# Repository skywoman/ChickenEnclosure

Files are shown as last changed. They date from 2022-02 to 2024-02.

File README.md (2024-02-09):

# ChickenEnclosure
Plans for enclosures for chickens, including 3D CAD models, manufacturing drawings, and sourcing guides. Variations for wheels, skids, and different sizes may be developed easily from a common base structure.

The first complete version of this enclosure uses u-bolts to attach the hoop to the frame.

[View the model in your browser here.](https://skywoman.github.io/ChickenEnclosure/Hoop%20Connection%20-%20U%20Bolts/UBoltModel.xhtml)

[Download the full 3D CAD model, bill of materials and sourcing guide, and manufacturing drawings here.](https://github.com/skywoman/ChickenEnclosure/releases/tag/v1.0.0) This includes each of the necessary components and sub-assemblies to build the full frame.

[The project webpage can be found here](https://skywoman.github.io/ChickenEnclosure/)

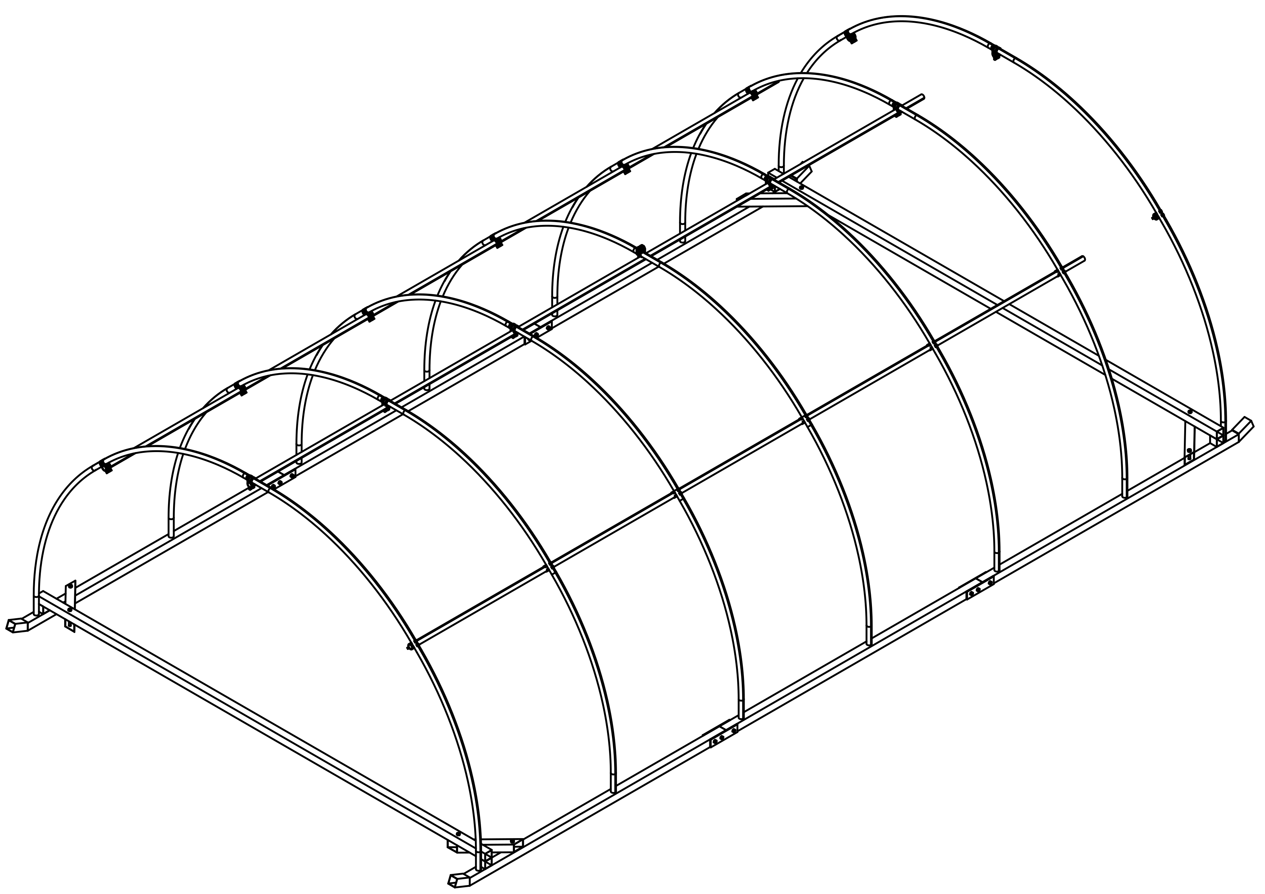
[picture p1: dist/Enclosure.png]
Wire Drawing


As designed, the materials cost is just over $1700 (USD). Depending on the conditions in your area, 2 inch square tube with a thinner wall can be substituted for 2.5 inch tube. Both materials and links are listed in the sourcing guide. Smaller, thinner-walled material will reduce the cost considerably at the expense of strength and durability. 

The design is inspired by the APPPA design, [which can be found here](https://www.apppa.org/resources/Documents/building%20a%20multi%20purpose%20pasture%20shelter.pdf).

CAD models are made in [FreeCAD](https://www.freecadweb.org), a free and open source modeling software.
Assemblies are made with the A2+ workbench, found in the Add-On Manager.

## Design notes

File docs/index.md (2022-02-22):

## Skywoman Chicken Enclosure
The Skywoman chicken enclosure is a simple-to-manufacture enclsoure for 300 birds. The design is simple enough to easily adapt to a variety of climate and predator conditions.

[VIEW THE MODEL HERE](model.xhtml)

Wire Drawing

The enclosure is a simple hoop house design, using square tubing for the base and round tubing for the hoops. The base model is moved on skids.

### Project Inspiration
The design of this enclosure is loosely based on the [APPPA design](https://www.apppa.org/resources/Documents/building%20a%20multi%20purpose%20pasture%20shelter.pdf), but has been modified to improve manufacturability and part sourcing.

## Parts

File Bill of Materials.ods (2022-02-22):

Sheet: Components
ITEM # | DESCRIPTION | QTY | SUPPLIER/MATERIAL | SUPPLIER IDENTIFIER | UNIT PRICE | TOTAL PRICE | CAD FILENAME
1 | Hoop Half Female | 7 |  |  |  | $0.00 | Hoop Half Female.FCStd
2 | Hoop Half Male | 7 |  |  |  | $0.00 | Hoop Half Male.FCStd
3 | Purlin | 3 |  |  |  | $0.00 | Purlin.FCStd
4 | Cross Connector Purlin Clamp | 21 | Tunnel Vision Hoops | https://www.tunnelvisionhoops.com/cross-connector-greenhouse-straps-purlin-clamps/ | $2.41 | $50.61 | Cross Connector Purlin Clamp.FCStd
5 | Front Bar | 2 | Square Tube | * | $129.02 | $258.03 | Front Bar.FCStd
6 | Side Front Bar | 2 | Square Tube | * | $73.72 | $147.45 | Side Front Bar.FCStd
7 | Spacer 2.5 Inch | 4 | Square Tube | * | $1.92 | $7.68 | Spacer 2.5 Inch.FCStd
8 | Corner Brace | 4 | Square Tube | * | $18.43 | $73.72 | Corner Brace.FCStd
9 | Side Rail Joint Plate | 8 | Steel Plate | * |  | $0.00 | Side Rail Joint Plate.FCStd
10 | Side Center Bar | 2 | Square Tube | * | $73.72 | $147.45 | Side Center Bar.FCStd
11 | Side Rear Bar | 2 | Square Tube | * | $73.72 | $147.45 | Side Rear Bar.FCStd
12 | Hex Head Bolt 0.500x5.50 Inch | 8 | Bolt Depot | 256 | $1.45 | $11.60 | Hex Head Bolt 0.500x5.50 Inch .FCStd
13 | Hex Head Bolt 0.500x3.50 Inch | 12 | Bolt Depot | 252 | $0.87 | $10.44 | Hex Head Bolt 0.500x3.50 Inch .FCStd
14 | Hex Nut 0.50 Inch | 20 | Bolt Depot | 2652 | $0.22 | $4.40 | Hex Nut 0.50 Inch.FCStd
15 | Skid Angled Foot | 4 | Square Tube | * |  | $0.00 | Skid Angled Foot.FCStd
16 | Hoop Attachment Peg | 14 | Lowes | https://www.lowes.com/pd/Mueller-Proline-5-1-2-in-L-x-1-2-in-x-1-2-in-dia-Black-Steel-Nipple-Fitting/3392746 | $4.58 | $64.12 | Hoop Attachment Peg.FCStd
 |  |  |  |  | GRAND TOTAL | $922.94

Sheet: Materials
Item # | Description | Vendor | Purchase Units | Purchase Quantity | Purchase Price | Usage Units | Usage Units per Purchased Unit | Price per Use Unit | URL
1 | Square Tube | OnlineMetals | Feet | 24 | $221.17 | Inches | 12 | $0.77 | https://www.onlinemetals.com/en/buy/carbon-steel/2-5-x-0-12-carbon-steel-square-tube-a500-a513-hot-rolled/pid/10352

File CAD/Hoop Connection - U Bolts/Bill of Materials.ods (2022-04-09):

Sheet: Components
 |  |  |  |  |  |  |  |  | Grand Total | $1,709.51
POS | QTY | DESCRIPTION | SUPPLIER | SUPP.IDENTNO | SUPP.DESCRIPTION | (FILENAME) | Raw Material Price per Foot | Length | Unit Price | Total Price
1 | 3 | Purlin |  |  |  | Purlin.FCStd | $2.00 | 24 | $47.95 | $143.86
2 | 21 | Cross Connector Purlin Clamp | Tunnel Vision Hoops | https://www.tunnelvisionhoops.com/cross-connector-greenhouse-straps-purlin-clamps/ |  | Cross Connector Purlin Clamp.FCStd |  |  | $2.41 | $50.61
3 | 28 | U Bolt 3/8 x 1-1/2 x | McMaster Carr | 8880T958 | 3/8-16 Thread Size, 2 ID | U Bolt.FCStd |  |  | $1.84 | $51.52
4 | 14 | HOOP HALF | Lowes | Item #103268 Model #58910235 | 10.5-ft L 17-Gauge Galvanized Steel Chain Link Fence Top Rail | Hoop Half.FCStd |  |  | $20.98 | $293.72
5 | 4 | CORNER BRACE | OnlineMetals.com | 10352 | 2.5 Inch x 0.12 Inch Carbon Steel Square Tube A500/A513 Hot Rolled | Corner Brace.FCStd | $9.21 | 1.75 | $16.12 | $64.50
6 | 8 | SIDE RAIL JOINT PLATE | OnlineMetals.com | 10031 | 0.25 Inch x 2.5 Inch Carbon Steel Rectangle Bar A36 Hot Rolled | Side Rail Joint Plate.FCStd | $4.27 | 0.833333333333333 | $3.56 | $28.44
7 | 8 | 1/2-13 5.5 Inch Hex Head Bolt | Bolt Depot | 256 | 1.45 | Hex Head Bolt 0.500x5.50 Inch .FCStd |  |  | $1.45 | $11.60
8 | 12 | 1/2-13 3.5 Inch Hex Head Bolt | Bolt Depot | 252 | 0.87 | Hex Head Bolt 0.500x3.50 Inch .FCStd |  |  | $0.87 | $10.44
9 | 20 | Hex Nut 1/2 Inch | Bolt Depot | 2652 | 0.22 | Hex Nut 0.50 Inch.FCStd |  |  | $0.22 | $4.40
10 | 2 | FRONT BAR | OnlineMetals.com | 10352 | 2.5 Inch x 0.12 Inch Carbon Steel Square Tube A500/A513 Hot Rolled | Front Bar.FCStd | $9.21 | 14 | $129.00 | $258.00
11 | 4 | SIDE FRONT BAR | OnlineMetals.com | 10352 | 2.5 Inch x 0.12 Inch Carbon Steel Square Tube A500/A513 Hot Rolled | Side Front Bar.FCStd | $9.21 | 8 | $73.71 | $294.85
12 | 4 | SKID ANGLED FOOT | OnlineMetals.com | 10352 | 2.5 Inch x 0.12 Inch Carbon Steel Square Tube A500/A513 Hot Rolled | Skid Angled Foot.FCStd | $9.21 | 6 | $55.29 | $221.14
13 | 14 | HOOP MOUNT BLOCK | OnlineMetals.com | 10352 | 2.5 Inch x 0.12 Inch Carbon Steel Square Tube A500/A513 Hot Rolled | Hoop Mount Block.FCStd | $9.21 | 1 | $9.21 | $129.00
14 | 2 | SIDE CENTER BAR | OnlineMetals.com | 10352 | 2.5 Inch x 0.12 Inch Carbon Steel Square Tube A500/A513 Hot Rolled | Side Center Bar.FCStd | $9.21 | 8 | $73.71 | $147.43

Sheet: Material
Material | Stock Length | Stock Price | Price per Foot | Link
2.5 Inch Square Tube 1/8 Wall | 24 | $221.14 | $9.21 | https://www.onlinemetals.com/en/buy/carbon-steel/2-5-x-0-12-carbon-steel-square-tube-a500-a513-hot-rolled/pid/10352
2 Inch Square Tube 1/16 Wall | 24 | 147.99 | $6.17 | https://www.onlinemetals.com/en/buy/carbon-steel/2-x-0-065-carbon-steel-square-tube-a500-a513-hot-rolled/pid/10339
0.25 Inch x 2.5 Inch Carbon Steel Rectangle Bar A36 Hot Rolled | 8 | 34.13 | $4.27 | https://www.onlinemetals.com/en/buy/carbon-steel/0-25-x-2-5-carbon-steel-rectangle-bar-a36-hot-rolled/pid/10031
Chain Link Top Rail | 10.5 | 20.98 | $2.00 | https://www.lowes.com/pd/Galvanized-Steel-Chain-Link-Fence-Top-Rail/999989216

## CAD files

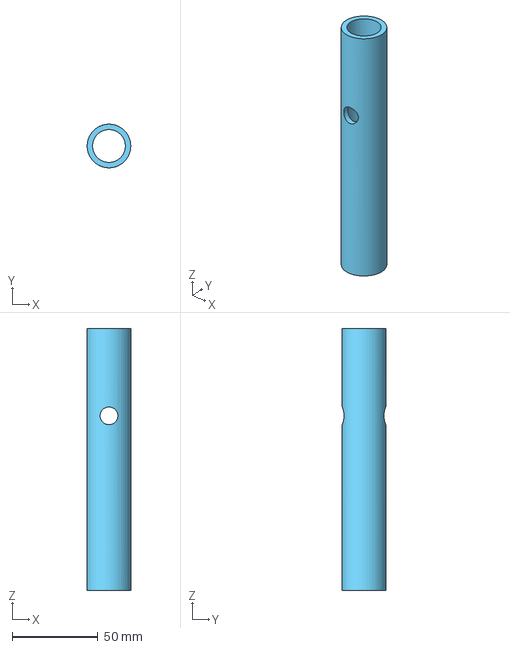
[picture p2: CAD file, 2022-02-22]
CAD/Hoop Attachment Peg.FCStd
25.4 x 25.4 x 152.4 mm

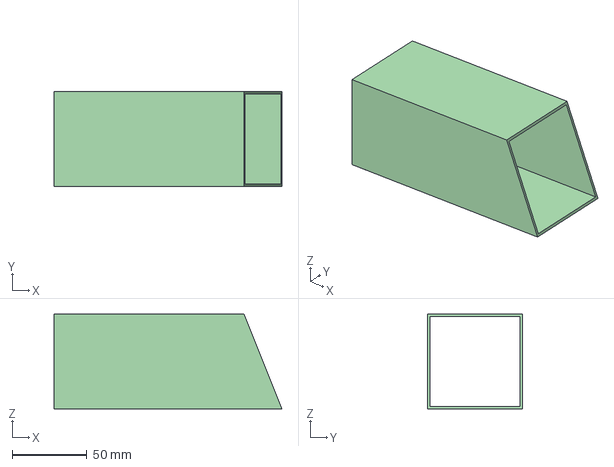
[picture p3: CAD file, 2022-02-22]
CAD/Skid Angled Foot.FCStd
152.4 x 63.5 x 63.5 mm

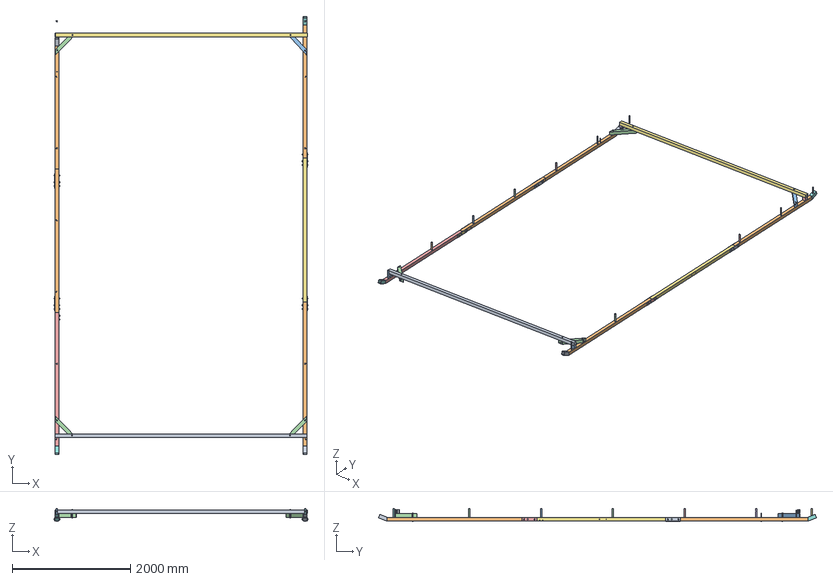
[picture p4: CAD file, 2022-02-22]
CAD/Frame.FCStd
4296.3 x 7420.4 x 224.1 mm
Front Bar_001
Side Front Bar_001
Spacer 2.5 Inch_001
Corner Brace_001
Side Rail Joint Plate_001
Side Rail Joint Plate_002
Side Center Bar_001
Side Rail Joint Plate_003
Side Rail Joint Plate_004
Side Rear Bar_001
Spacer 2.5 Inch_002
Corner Brace_002
Side Front Bar_002
Side Rail Joint Plate_005
Side Rail Joint Plate_006
Side Rail Joint Plate_007
Side Rail Joint Plate_008
Side Center Bar_002
Corner Brace_003
Corner Brace_004
Spacer 2.5 Inch_003
Spacer 2.5 Inch_004
Front Bar_002
Hex Head Bolt 0.500x5.50 Inch _001
Hex Head Bolt 0.500x5.50 Inch _002
Hex Head Bolt 0.500x5.50 Inch _003
Hex Head Bolt 0.500x5.50 Inch _004
Hex Head Bolt 0.500x5.50 Inch _005
Hex Head Bolt 0.500x5.50 Inch _006
Hex Head Bolt 0.500x5.50 Inch _007
Hex Head Bolt 0.500x5.50 Inch _008
Hex Head Bolt 0.500x3.50 Inch _001
Hex Head Bolt 0.500x3.50 Inch _002
Hex Head Bolt 0.500x3.50 Inch _003
Hex Head Bolt 0.500x3.50 Inch _004
Hex Head Bolt 0.500x3.50 Inch _005
Hex Head Bolt 0.500x3.50 Inch _006
Hex Head Bolt 0.500x3.50 Inch _007
Hex Head Bolt 0.500x3.50 Inch _008
Hex Head Bolt 0.500x3.50 Inch _009
Hex Head Bolt 0.500x3.50 Inch _010
Hex Head Bolt 0.500x3.50 Inch _011
Hex Head Bolt 0.500x3.50 Inch _012
Hex Nut 0.50 Inch_001
Hex Nut 0.50 Inch_002
Hex Nut 0.50 Inch_003
Hex Nut 0.50 Inch_004
Hex Nut 0.50 Inch_005
Hex Nut 0.50 Inch_006
Hex Nut 0.50 Inch_007
Hex Nut 0.50 Inch_008
Hex Nut 0.50 Inch_009
Hex Nut 0.50 Inch_010
Hex Nut 0.50 Inch_011
Hex Nut 0.50 Inch_012
Hex Nut 0.50 Inch_013
Hex Nut 0.50 Inch_014
Hex Nut 0.50 Inch_015
Hex Nut 0.50 Inch_016
Hex Nut 0.50 Inch_017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

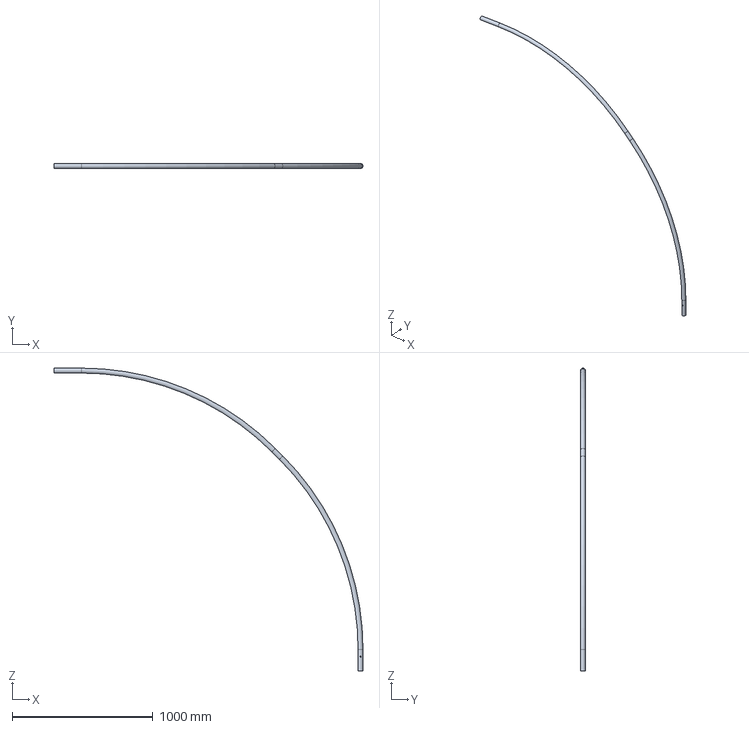
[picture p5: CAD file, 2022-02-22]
CAD/Hoop Half Female.FCStd
2195.6 x 35.0 x 2151.1 mm

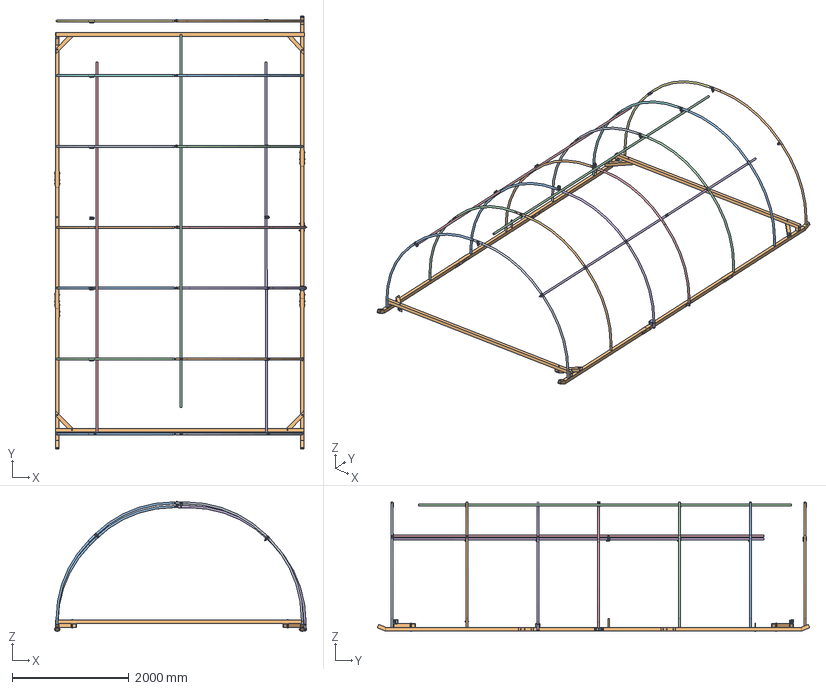
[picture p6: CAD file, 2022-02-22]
CAD/Chicken Enclosure.FCStd
4323.5 x 7420.4 x 2232.8 mm
Hoop Half Female_001
Hoop Half Female_002
Hoop Half Male_001
Purlin_001
Purlin_002
Purlin_003
Cross Connector Purlin Clamp_001
Cross Connector Purlin Clamp_002
Cross Connector Purlin Clamp_003
Hoop Half Female_003
Hoop Half Female_004
Hoop Half Female_005
Hoop Half Female_006
Hoop Half Female_007
Hoop Half Male_002
Hoop Half Male_003
Hoop Half Male_004
Hoop Half Male_005
Hoop Half Male_006
Hoop Half Male_007
Cross Connector Purlin Clamp_004
Cross Connector Purlin Clamp_005
Cross Connector Purlin Clamp_006
Cross Connector Purlin Clamp_007
Cross Connector Purlin Clamp_008
Frame_001
Cross Connector Purlin Clamp_009
Cross Connector Purlin Clamp_010
Cross Connector Purlin Clamp_011
Cross Connector Purlin Clamp_012
Cross Connector Purlin Clamp_013
Cross Connector Purlin Clamp_014
Cross Connector Purlin Clamp_015
Cross Connector Purlin Clamp_016
Cross Connector Purlin Clamp_017
Cross Connector Purlin Clamp_018
Cross Connector Purlin Clamp_019
Cross Connector Purlin Clamp_020
Cross Connector Purlin Clamp_021
3/8inx2in-Screw
3/8in-Nut
U Bolt_001
Hoop Mount Block_001
U Bolt_002
3/8in-Nut061
3/8in-Nut062
3/8in-Nut063
3/8in-Nut064
Hoop Attachment Bracket_001
Hex Head Bolt 0.500x3.50 Inch_001
Hex Head Bolt 0.500x3.50 Inch_002
Hex Nut 0.50 Inch_001
Hex Nut 0.50 Inch_002

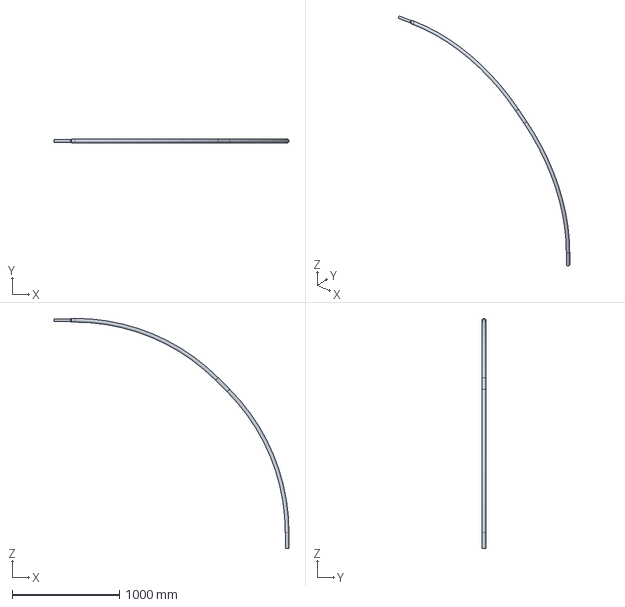
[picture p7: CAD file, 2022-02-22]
CAD/Hoop Half Male.FCStd
2195.6 x 35.6 x 2151.1 mm

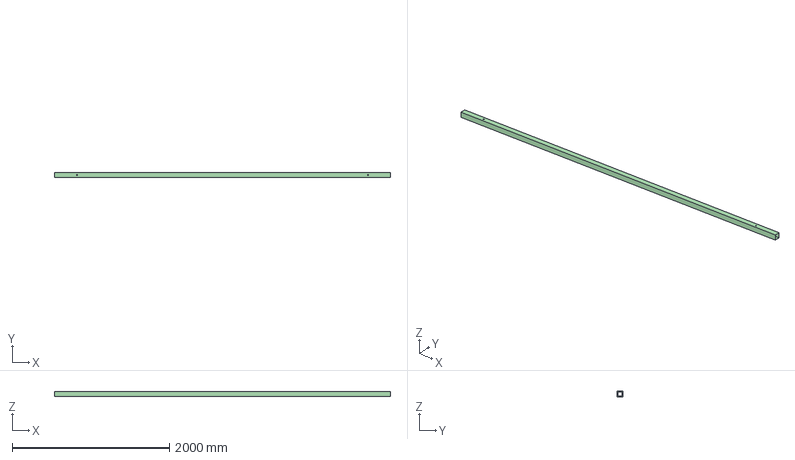
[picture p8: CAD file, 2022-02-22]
CAD/Front Bar.FCStd
4267.2 x 63.5 x 63.5 mm

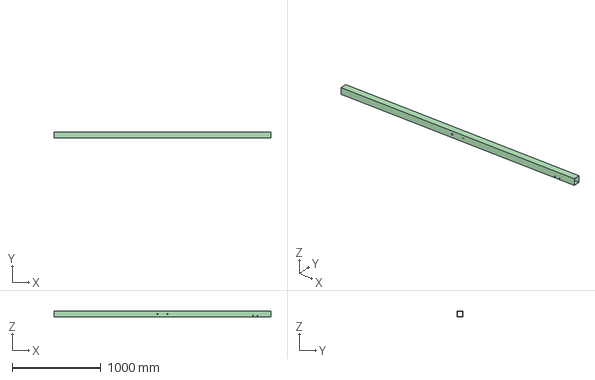
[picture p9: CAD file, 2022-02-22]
CAD/Side Center Bar.FCStd
2438.4 x 63.5 x 63.5 mm

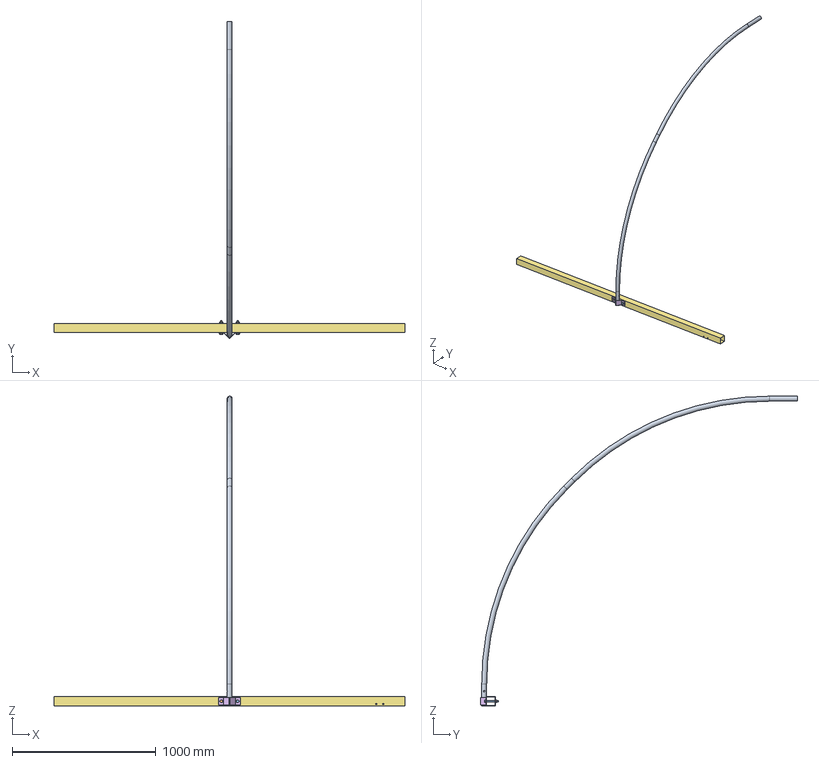
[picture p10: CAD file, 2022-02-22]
CAD/Hoop Attachment Bent Plate.FCStd
2438.4 x 2205.5 x 2151.1 mm
Hoop Half Female_006
Hex Head Bolt 0.500x3.50 Inch_001
Hex Head Bolt 0.500x3.50 Inch_002
Hex Nut 0.50 Inch_001
Hex Nut 0.50 Inch_002
Hoop Attachment Bracket_001
Side Center Bar_001

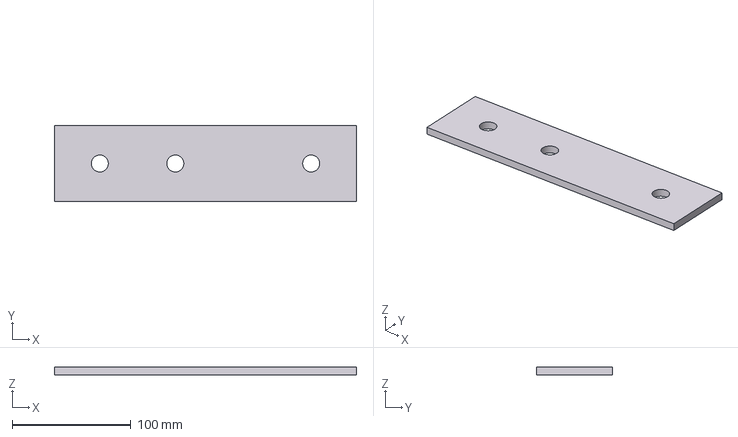
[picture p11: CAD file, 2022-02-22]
CAD/Side Rail Joint Plate.FCStd
254.0 x 63.5 x 6.35 mm

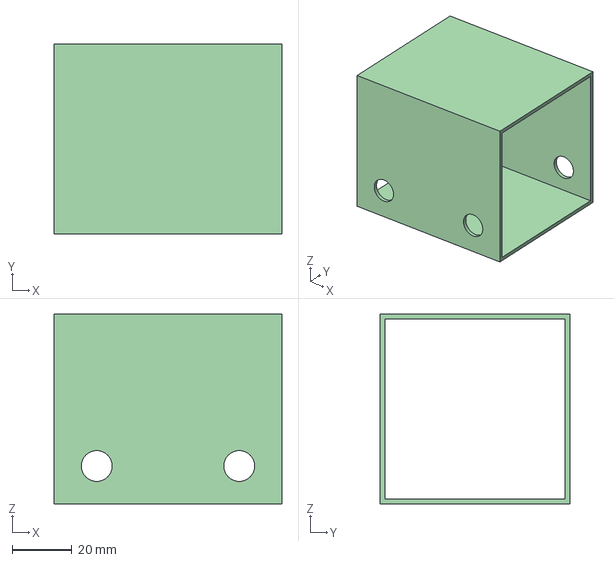
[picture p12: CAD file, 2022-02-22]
CAD/Hoop Mount Block.FCStd
76.2 x 63.5 x 63.5 mm

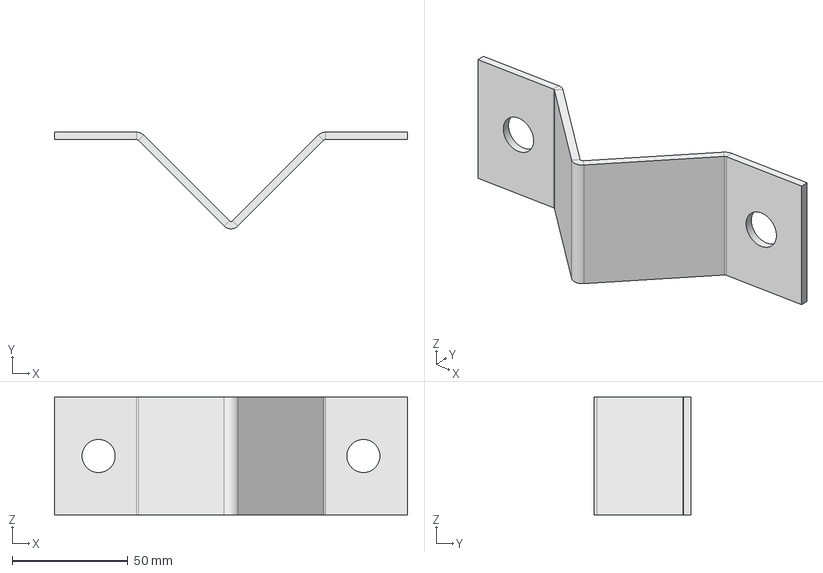
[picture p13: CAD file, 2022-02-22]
CAD/Hoop Attachment Bracket.FCStd
152.4 x 41.7 x 50.8 mm

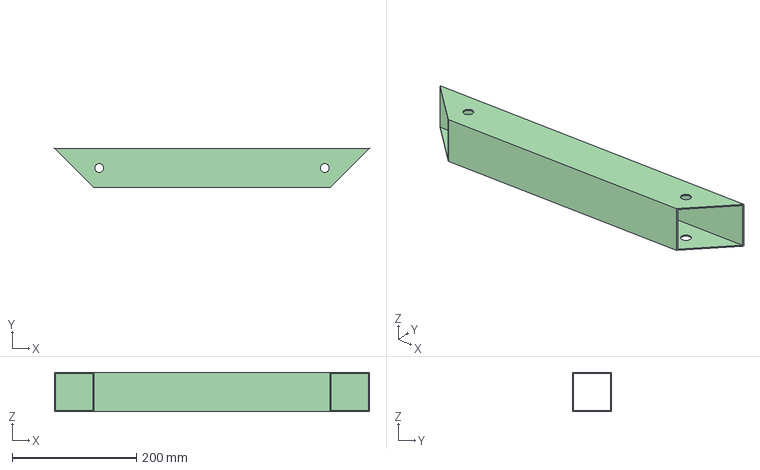
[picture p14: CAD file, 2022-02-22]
CAD/Corner Brace.FCStd
508.0 x 63.5 x 63.5 mm

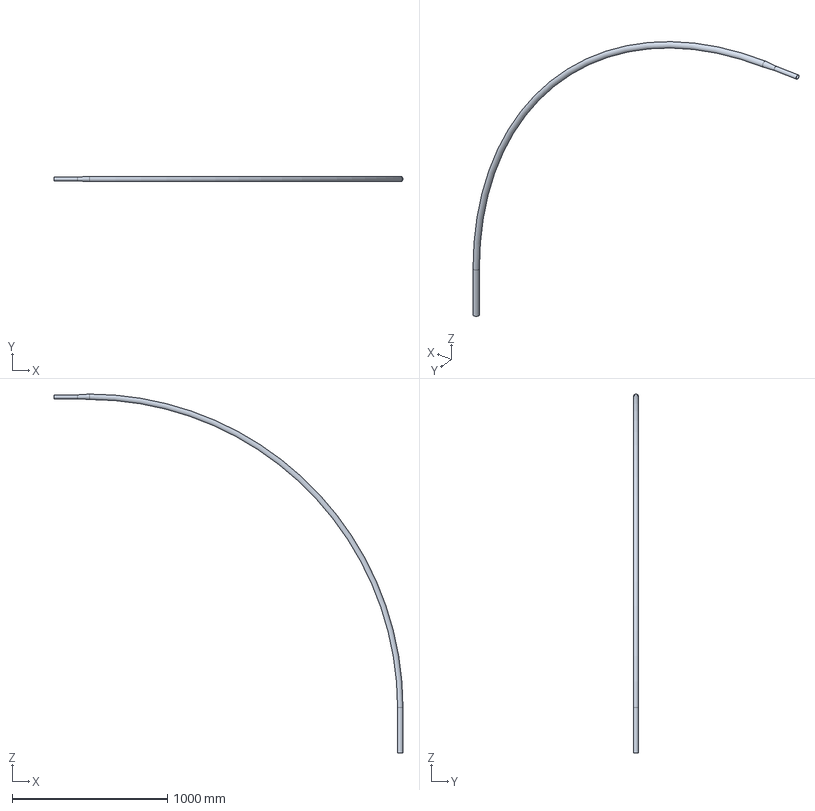
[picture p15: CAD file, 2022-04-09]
CAD/Hoop Connection - U Bolts/Hoop Half.FCStd
2248.0 x 35.0 x 2311.5 mm

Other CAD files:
CAD/Side Front Bar.FCStd
CAD/Hoop Connection - U Bolts/Side Center Bar.FCStd
CAD/Hoop Connection - U Bolts/Hoop Mount Block.FCStd
CAD/U Bolt.FCStd
CAD/Hex Head Bolt 0.500x3.50 Inch.FCStd
CAD/Hoop Attachment Bolted Peg.FCStd
CAD/Hoop Connection - U Bolts/Chicken Enclosure U Bolt.FCStd
CAD/Hoop Connection - U Bolts/Corner Brace.FCStd
CAD/Hoop Connection - U Bolts/Cross Connector Purlin Clamp.FCStd
CAD/Hoop Connection - U Bolts/Frame Welded End.FCStd
CAD/Hoop Connection - U Bolts/Frame.FCStd
CAD/Hoop Connection - U Bolts/Front Bar.FCStd
CAD/Hoop Connection - U Bolts/Hex Head Bolt 0.500x3.50 Inch .FCStd
CAD/Hoop Connection - U Bolts/Hex Head Bolt 0.500x5.50 Inch .FCStd
CAD/Hoop Connection - U Bolts/Hex Nut 0.50 Inch.FCStd
CAD/Hoop Connection - U Bolts/Purlin.FCStd
CAD/Hoop Connection - U Bolts/Side Bar Welded.FCStd
CAD/Hoop Connection - U Bolts/Side Front Bar.FCStd
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

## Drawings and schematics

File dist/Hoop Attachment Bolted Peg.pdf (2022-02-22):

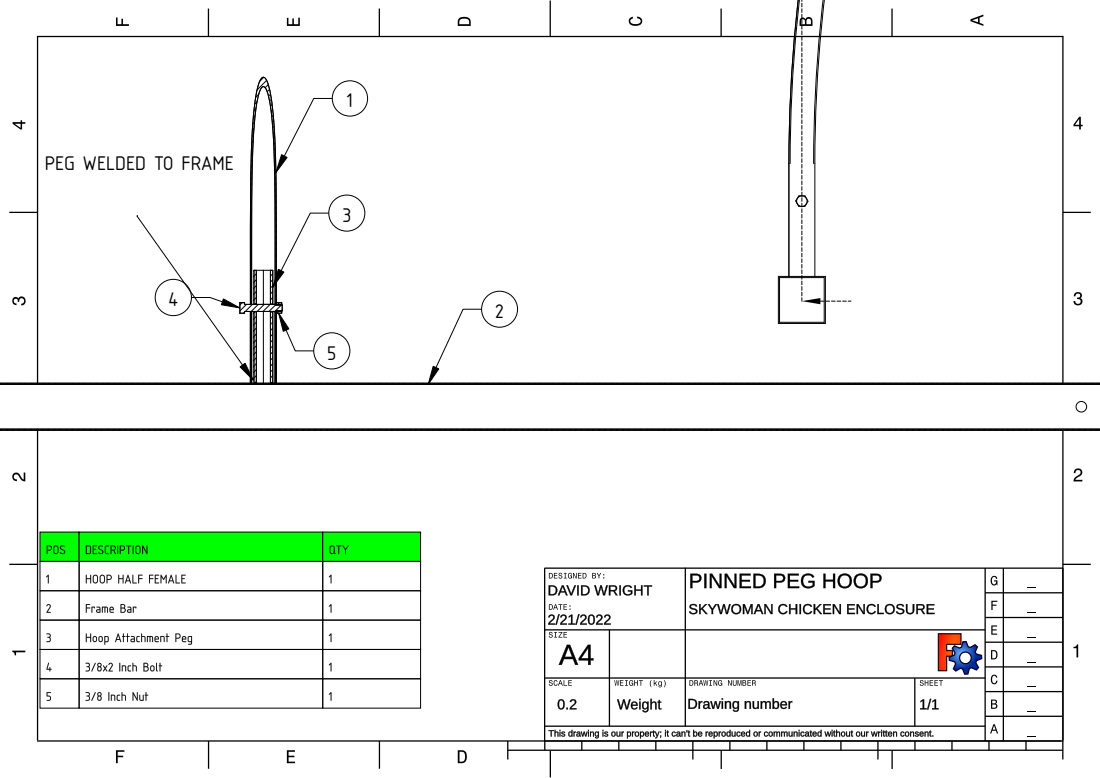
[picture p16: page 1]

PEG WELDED TO FRAME

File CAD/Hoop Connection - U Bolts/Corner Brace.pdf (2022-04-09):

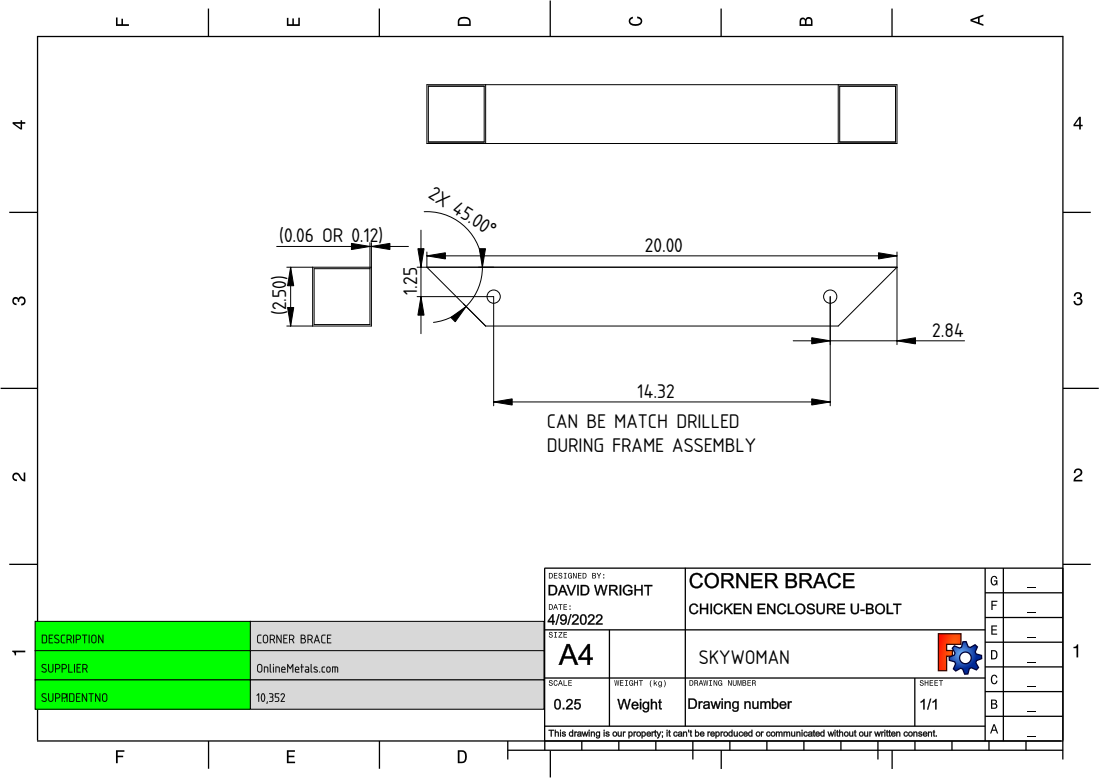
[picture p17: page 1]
SKYWOMAN

CAN BE MATCH DRILLED
DURING FRAME ASSEMBLY

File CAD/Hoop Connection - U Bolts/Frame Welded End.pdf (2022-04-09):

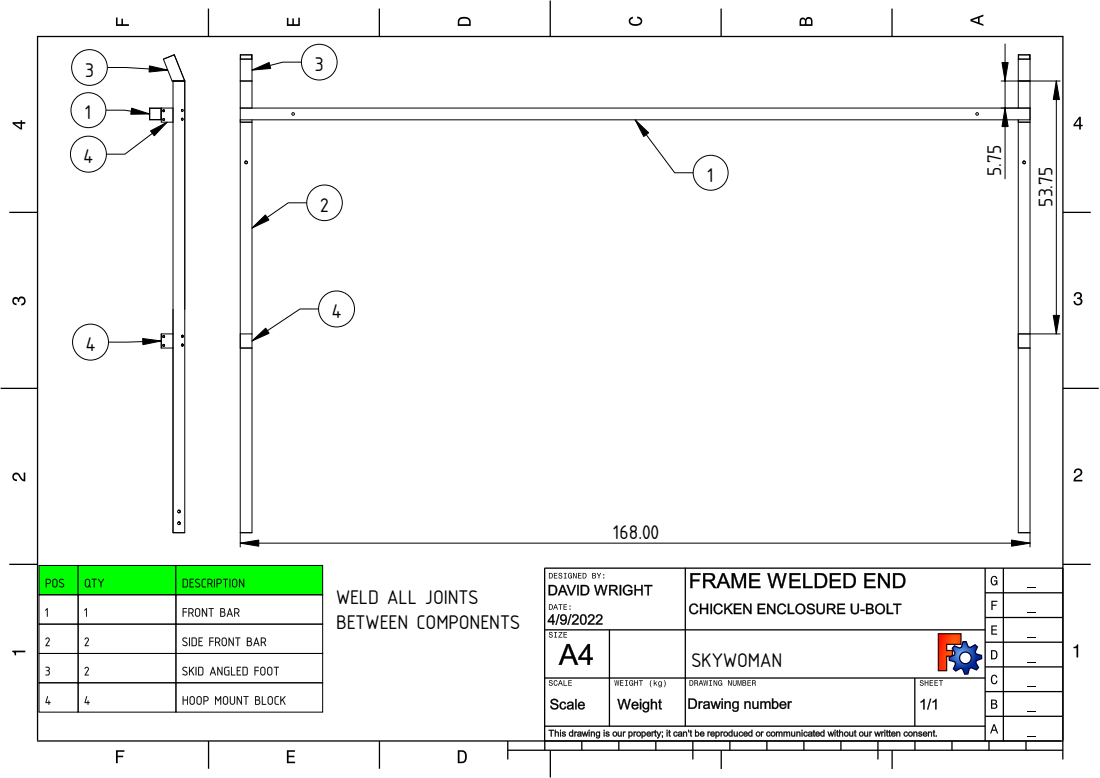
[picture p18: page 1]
SKYWOMAN

WELD ALL JOINTS
BETWEEN COMPONENTS

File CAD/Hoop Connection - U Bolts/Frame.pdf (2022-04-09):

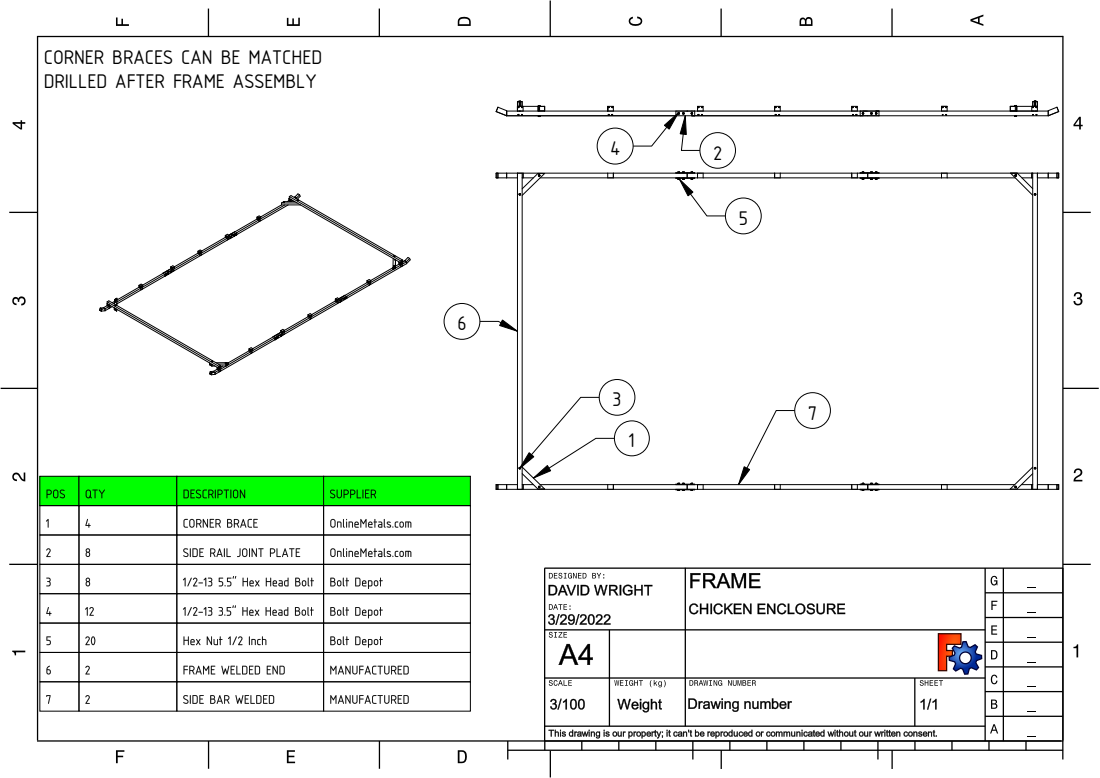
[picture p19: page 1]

CORNER BRACES CAN BE MATCHED
DRILLED AFTER FRAME ASSEMBLY

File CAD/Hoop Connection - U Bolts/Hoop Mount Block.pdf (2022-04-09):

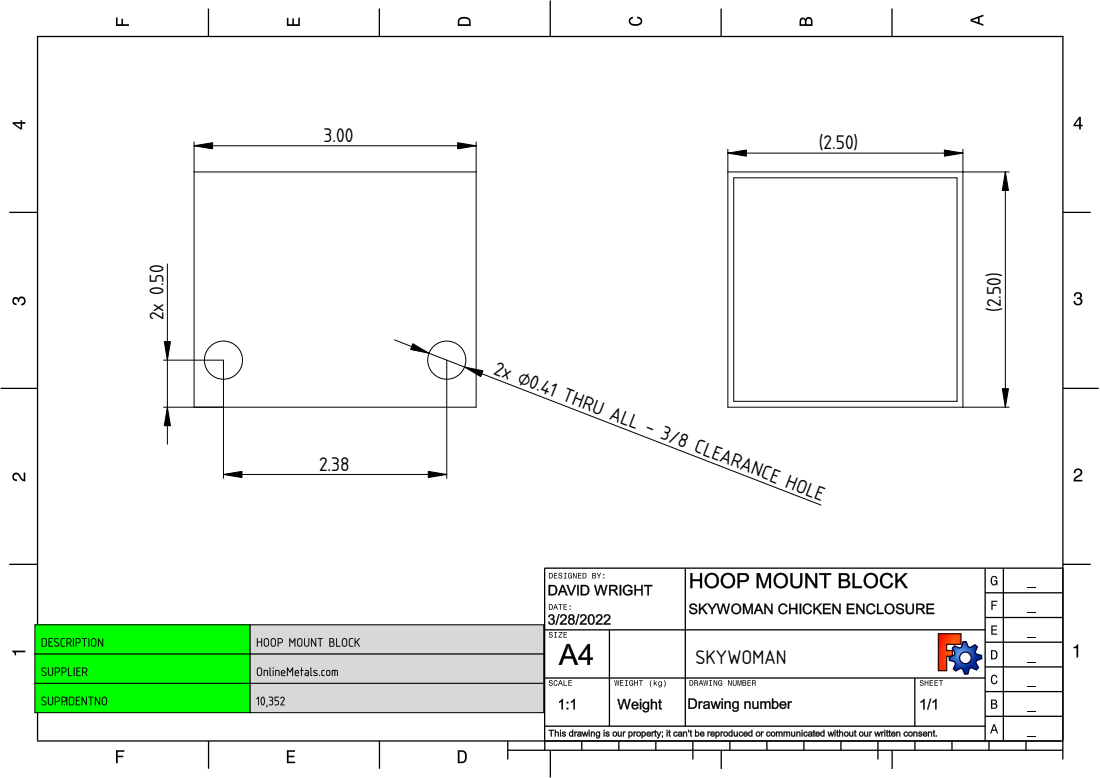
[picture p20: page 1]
SKYWOMAN

2x ⌀0.41 THRU ALL - 3/8 CLEARANCE HOLE

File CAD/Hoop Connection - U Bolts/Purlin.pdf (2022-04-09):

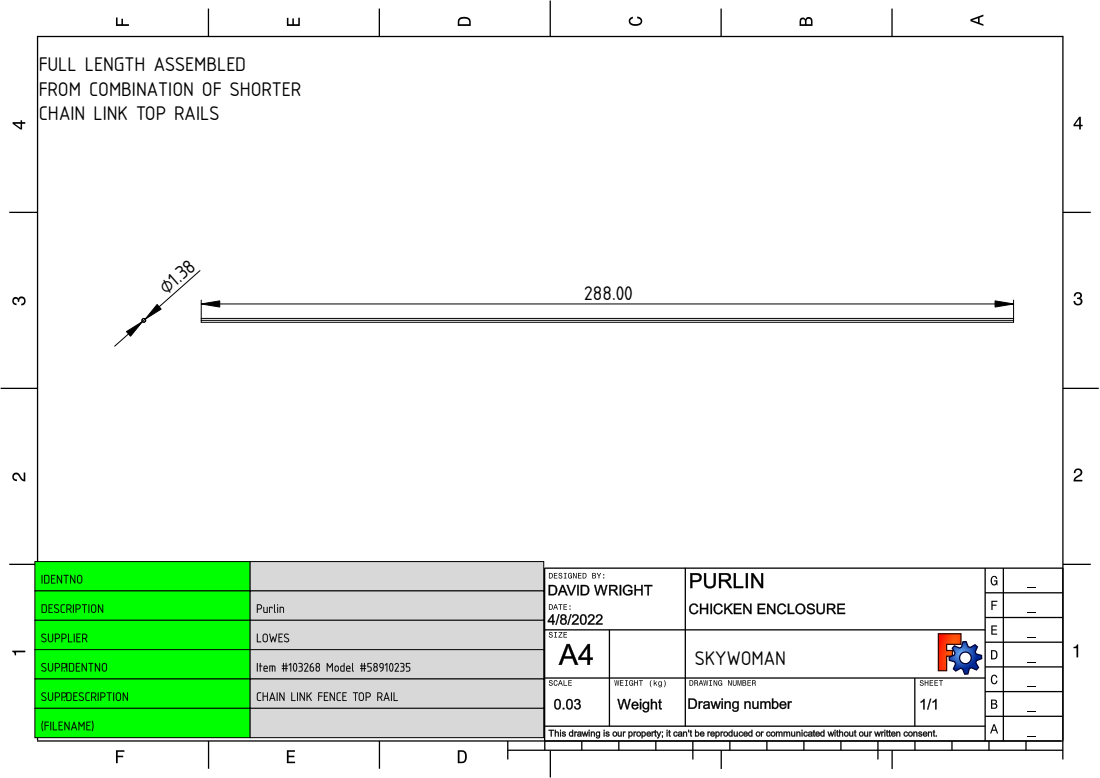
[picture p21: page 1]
SKYWOMAN

FULL LENGTH ASSEMBLED
FROM COMBINATION OF SHORTER
CHAIN LINK TOP RAILS

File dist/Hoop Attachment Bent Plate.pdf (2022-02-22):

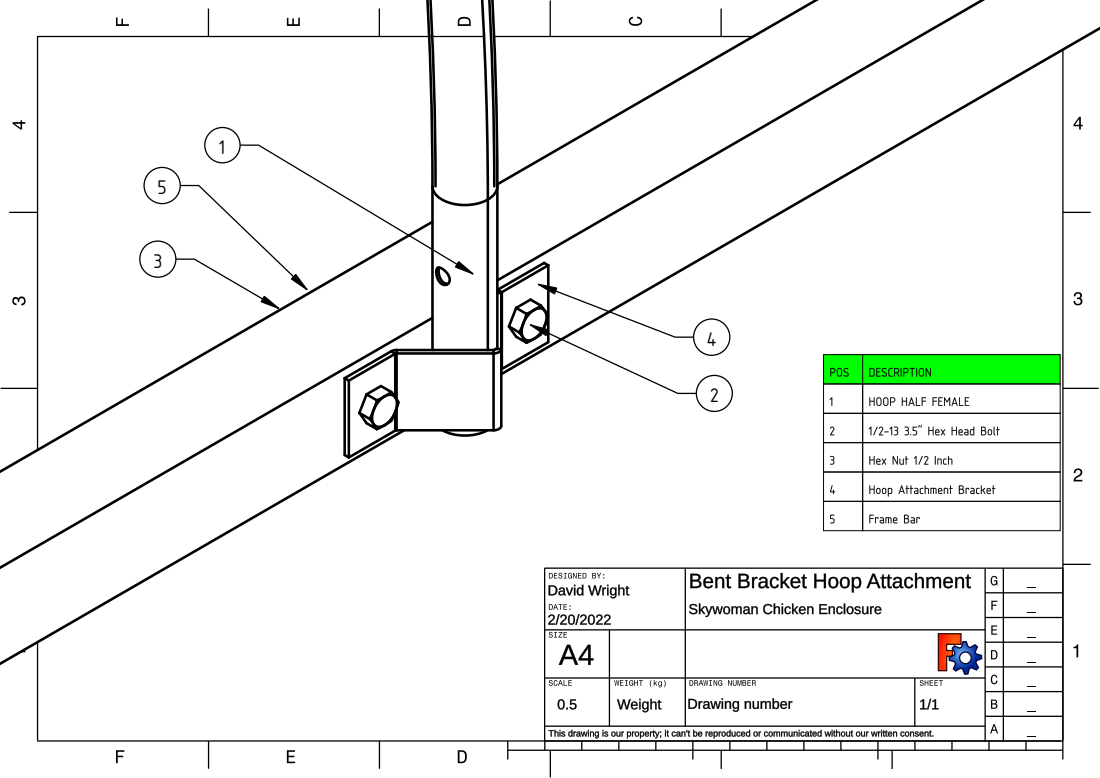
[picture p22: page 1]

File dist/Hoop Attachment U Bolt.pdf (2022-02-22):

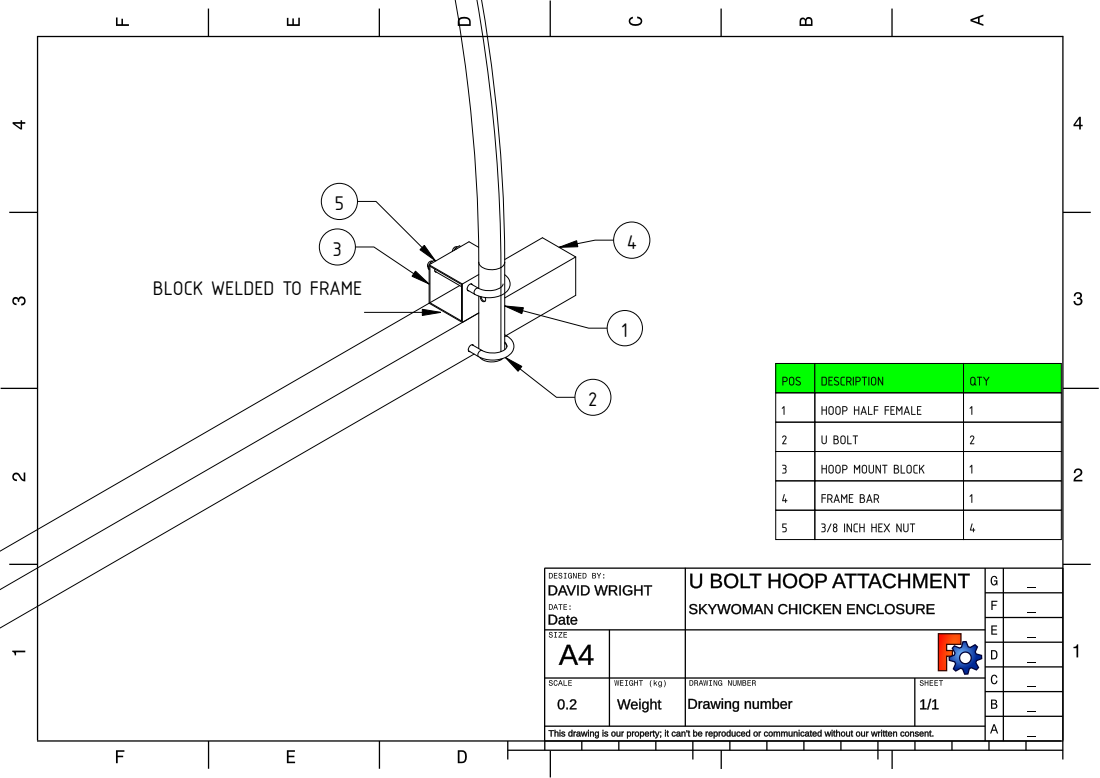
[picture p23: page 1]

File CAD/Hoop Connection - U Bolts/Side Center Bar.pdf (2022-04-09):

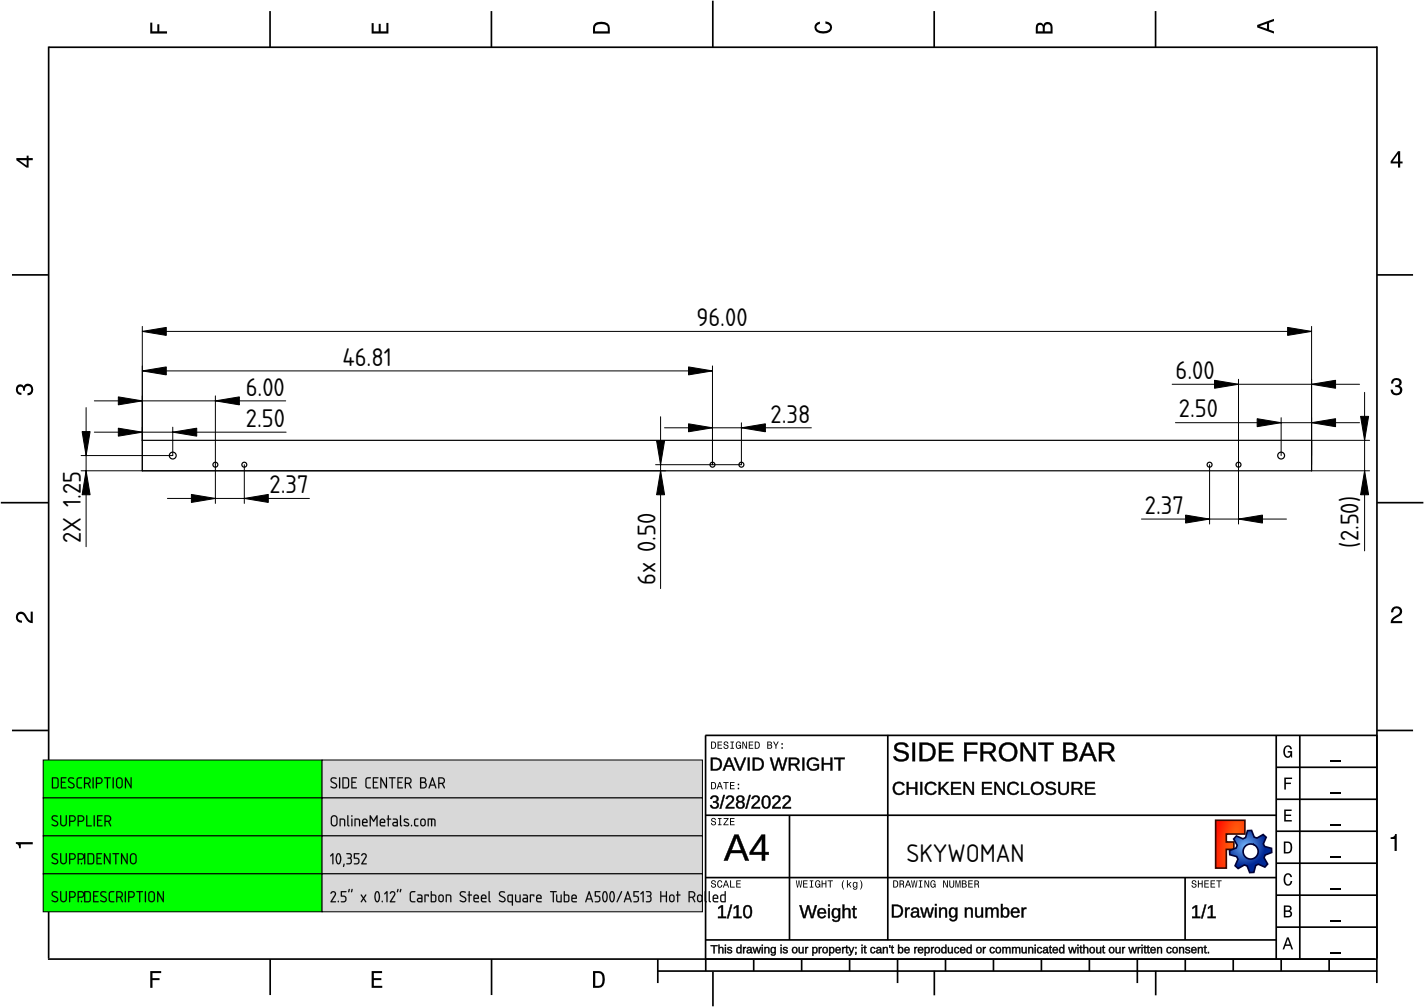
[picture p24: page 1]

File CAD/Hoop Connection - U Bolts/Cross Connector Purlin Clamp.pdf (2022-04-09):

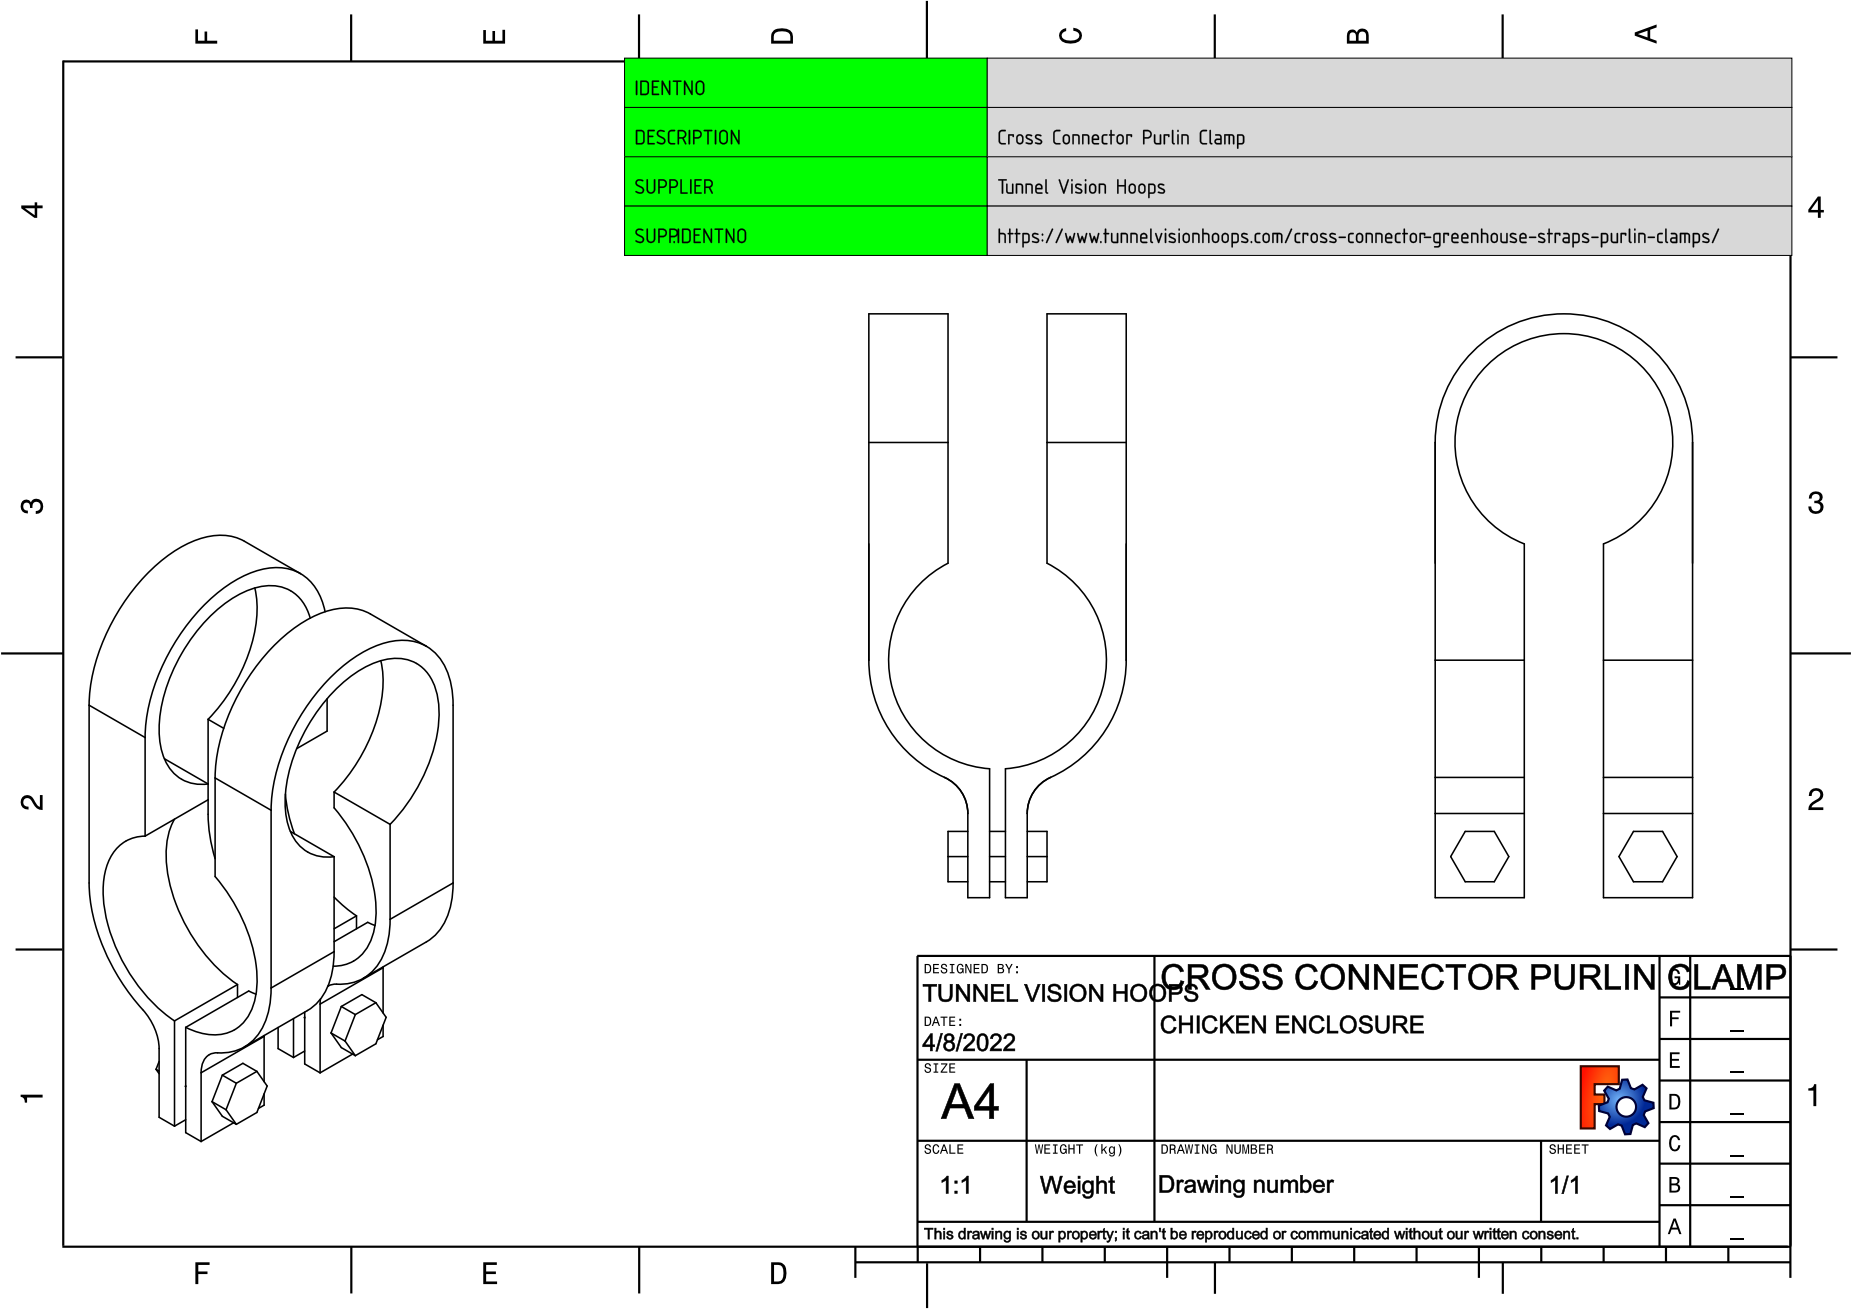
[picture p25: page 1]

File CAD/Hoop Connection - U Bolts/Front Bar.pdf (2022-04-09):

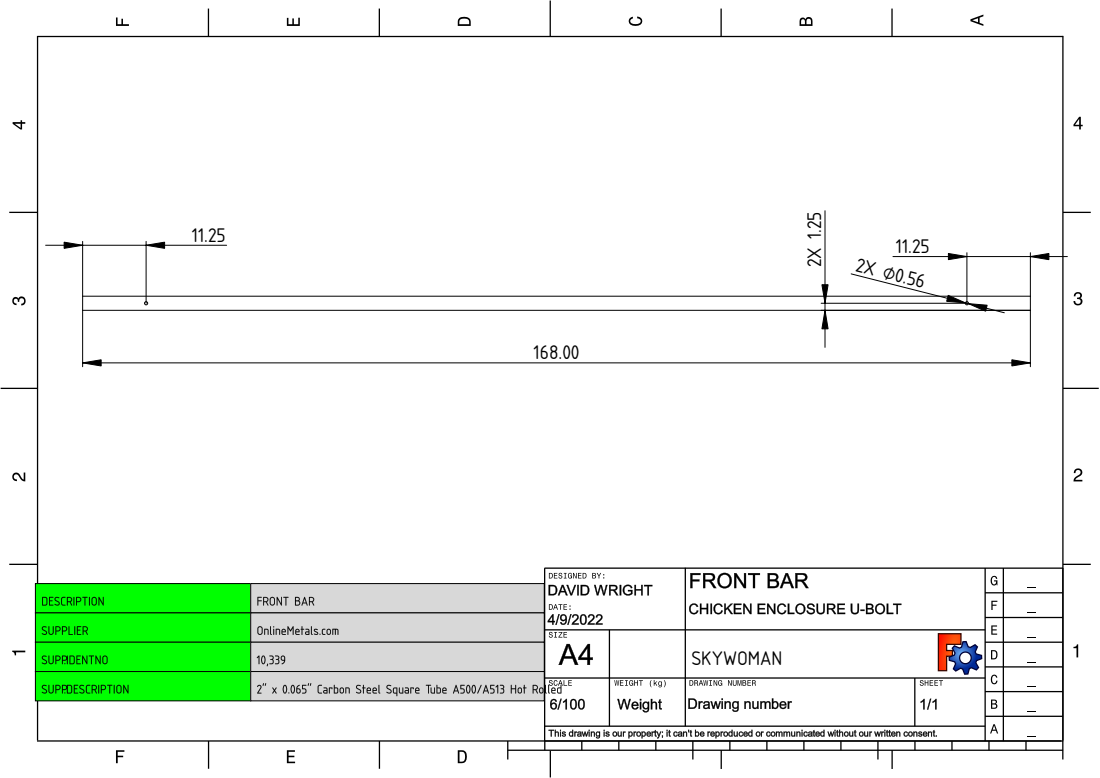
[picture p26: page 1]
SKYWOMAN

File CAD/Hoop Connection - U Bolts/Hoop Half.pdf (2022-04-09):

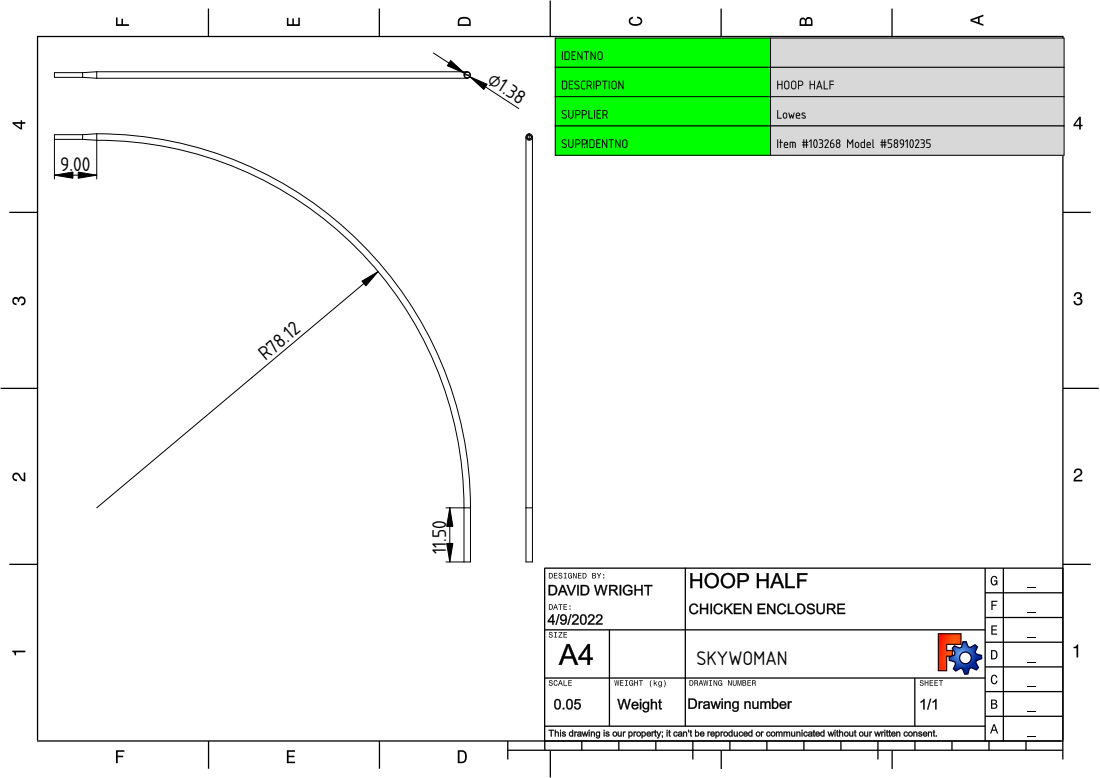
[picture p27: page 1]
SKYWOMAN

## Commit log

2022-01-31 Initial Frame Model
    [Corner Brace.FCStd, Frame.FCStd, Front Bar.FCStd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]
2022-01-31 Included design inspiration and CAD details.
2022-02-06 Added hoops and connectors
    [Chicken Enclosure.FCStd, Corner Brace.FCStd, Cross Connector Purlin Clamp.FCStd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]
2022-02-06 Updated README and added assembly drawing.
    [Chicken Enclosure.FCStd]
2022-02-22 Updated hoop attachment methods
    [Bill of Materials.ods, Chicken Enclosure.FCStd, Corner Brace.FCStd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]
2022-04-04 Added initial model variation
    [Bill of Materials.ods, Chicken Enclosure U Bolt.FCStd, Corner Brace.FCStd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]
2022-04-08 Updated u Bolt sourcing and size
    [Chicken Enclosure U Bolt.FCStd, Frame.FCStd, Hoop Half.FCStd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]
2022-04-09 Finalized Drawings
    [Bill of Materials.ods, Chicken Enclosure U Bolt.FCStd, Corner Brace.FCStd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]
2022-04-09 Removed unused files
    [Hoop Attachment U Bolts.FCStd, Side Center Bar.FCStd, Side Rear Bar.FCStd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]
